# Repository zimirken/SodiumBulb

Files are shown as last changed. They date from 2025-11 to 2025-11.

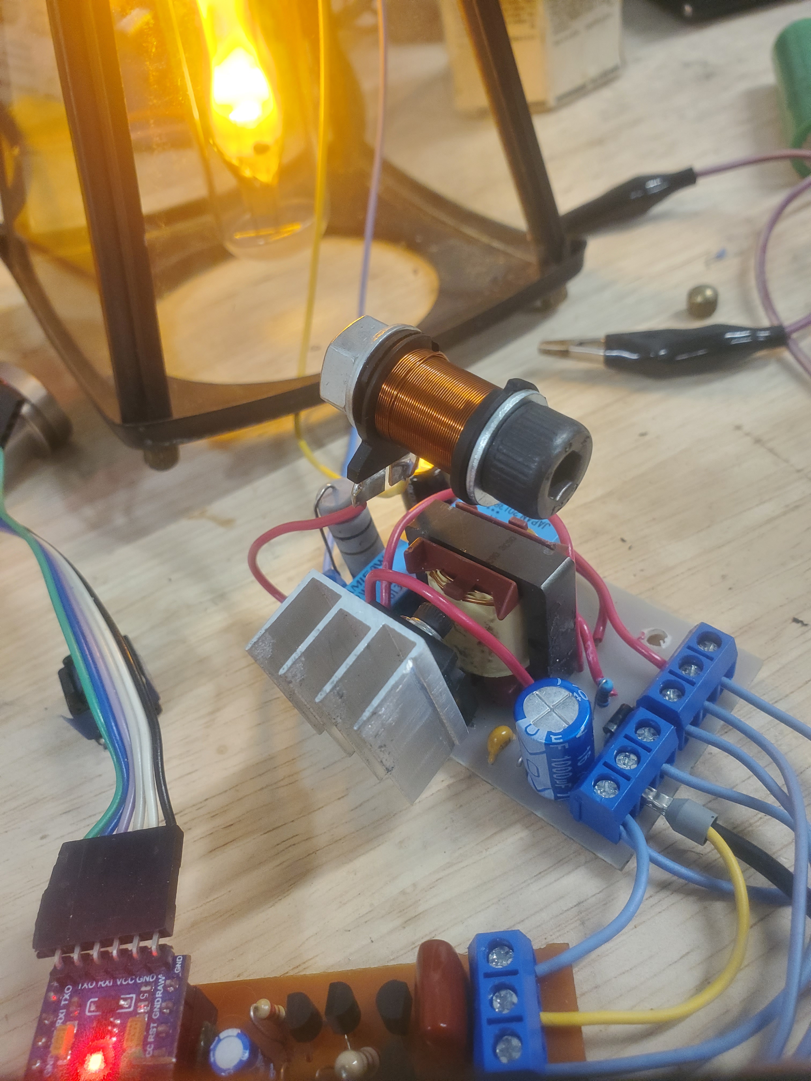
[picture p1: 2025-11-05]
20231208_142537.jpg

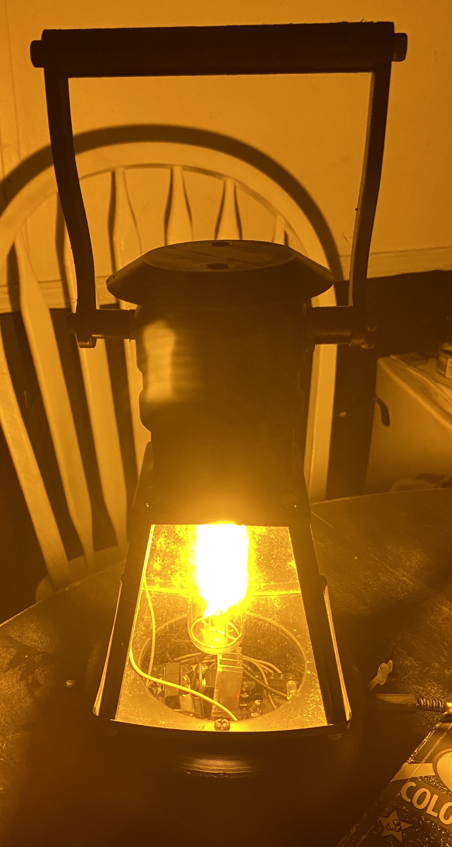
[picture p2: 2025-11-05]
IMG_0919.jpg

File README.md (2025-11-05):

# SodiumBulb
low pressure sodium vapor bulb
This is designed to drive a GP20NA or GP20ND low pressure sodium vapor bulb. 

These bulbs normally run on 15-20 volts at 1-2 amps. However, ignition is much more difficult. They require an ignition pulse of >400 volts with oomph behind it for a second or two in order to jump the gap between the main electrodes. This made designing a compact battery powered driver very difficult.

There is only one step up transformer in the circuit that serves dual purposes. During normal operation the secondary is disconnected and the primary is used as an inductor in a boost converter to generate the 15-20 volts to power the lamp. However during ignition, relays connect the secondary of the transformer to the bulb, and then the primary is driven HARD to get a discharge going across the electrode gap. The transformer and mosfet will overheat rapidly during this, but it only takes a couple seconds. It's also quite fun, as it gives you the feeling of igniting a flame lantern. When the lamp isn't ignited, the boost converter maintains the capacitor voltage at 35 volts. This extra voltage buffer gives the bulb a bit of extra juice to keep it lit while switching from ignite to drive.

The transformer was salvaged from a power supply, should be about a 10x step up. A transformer from one of those chinese 12V to 350V DC-DC boost converter boards should work. You will have to experiment with bulb polarity when hooking it to the circuit, Mine ignited much easier one way vs the other. NOT SHOWN on the schematic(but shown in pictures) is an inductor in series with the bulb. It's literally a coil of wire around an 8mm steel bolt. For me it made the bulb less likely to go out randomly, but wasn't required. In fact it looks like I might have not even included it in the final build. There's an enable terminal block, and an ignite terminal block. Jump the enable pins to enable the whole thing. Put a pushbutton switch on the ignite pins for igniting the bulb. The circuit and program has built in low voltage cutoff.

The 12 volt power in doesn't have its own connector on the boards, it is connected to pins 1(gnd) and 2(12v) on the GPG terminal block on the power board. Study the schematic and pictures to confirm.

Bulb: https://www.aliexpress.us/item/2255801048097192.html

A step file for the lantern assembly I built is included, but likely won't be super helpful. It's based on an outdoor house lamp I found at a thrift store.

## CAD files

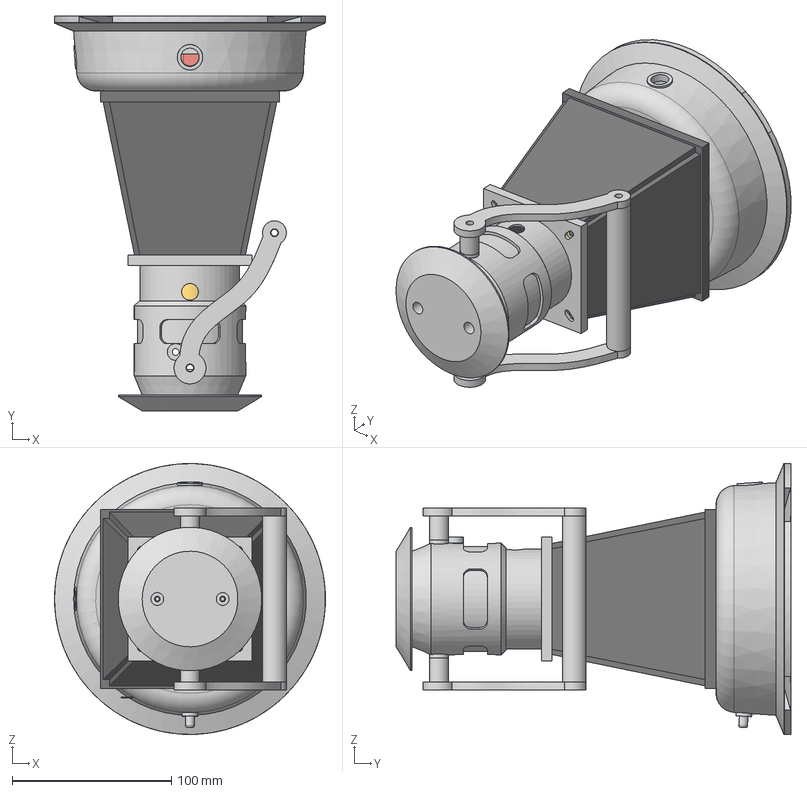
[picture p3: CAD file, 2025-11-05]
sodium lantern v25.step
170.0 x 247.8 x 170.0 mm
glass
bottom flange
bulb
socket
spacer x 2
top cap
bottom cap
base 1
base lid
decorative top cap
lower handle spacer x 2
handle arm x 2
handle
switch V-153-1C25
ignition button

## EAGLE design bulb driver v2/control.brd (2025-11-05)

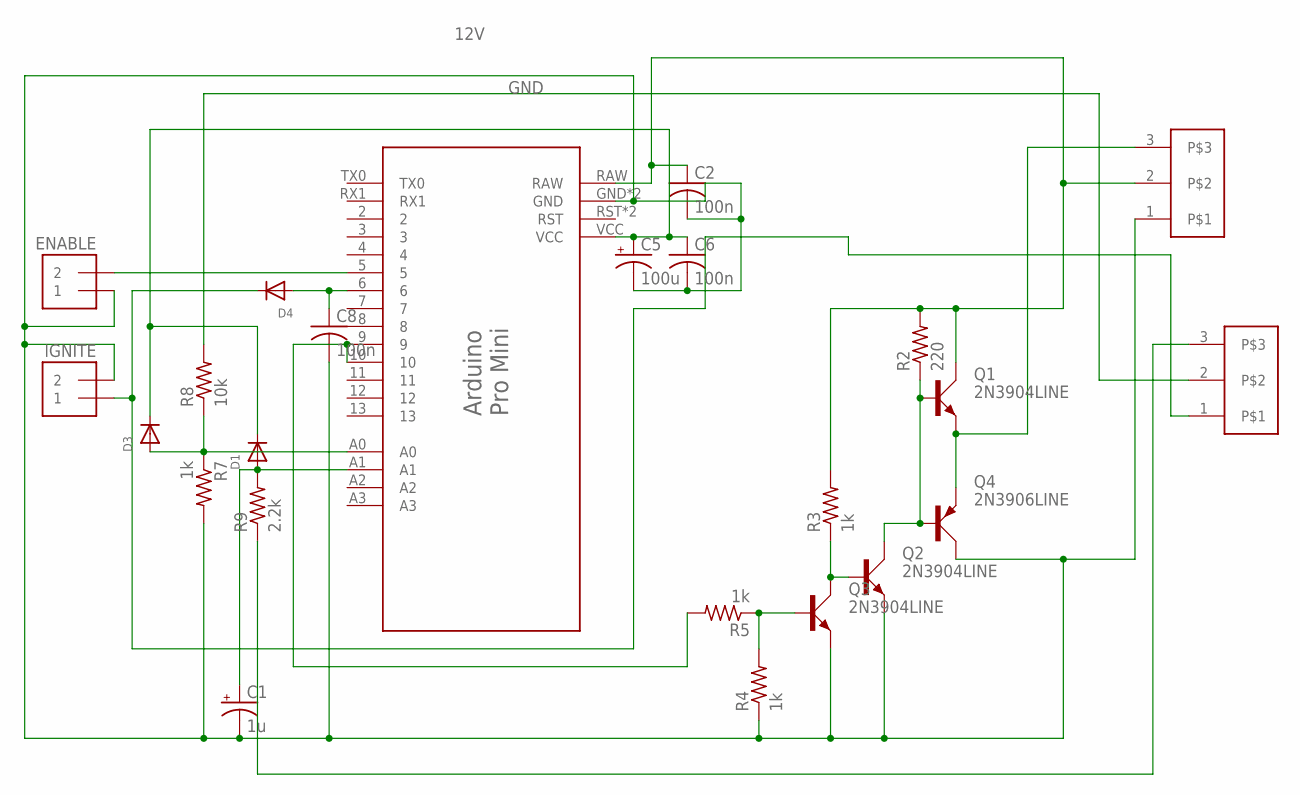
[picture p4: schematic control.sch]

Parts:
C1: 1u; E2,5-6
C2: 100n; C050-030X075
C5: 100u; E2,5-6
C6, C8: 100n; C050-025X075
D1, D3, D4: DIODEDO-1N4148; DO-1N4148
ENABLE: 1X2_12PINS; 1X2PINS
GPG: 1X3_123
IGNITE: 1X2_12HORZPINS; 1X2HORZ
IVI: 1X3_123
Q1, Q2, Q3: 2N3904LINE; TO92-LINE
Q4: 2N3906LINE; TO92-LINE
R2: 220; 0204/5
R3, R4: 1k; 0207/2V
R5: 1k; 0207/15
R7: 1k; 0207/5V
R8: 10k; 0207/15
R9: 2.2k; 0207/12
U$1: PRO_MINI

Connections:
12V: C2.1, GPG.2, Q1.C, R2.2, R3.2, U$1.RAW
GND: C1.-, C2.2, C5.-, C6.2, C8.2, ENABLE.1, GPG.1, IGNITE.2, Q2.E, Q3.E, Q4.C, R4.1, R7.2, U$1.GND, U$1.GND1 (GND)
unnamed: D3.A, R7.1, R8.1, U$1.A0
unnamed: C5.+, C6.1, D1.C, D3.C, U$1.VCC
unnamed: GPG.3, Q1.E, Q4.E
unnamed: Q3.B, R4.2, R5.1
unnamed: Q1.B, Q2.C, Q4.B, R2.1
unnamed: Q2.B, Q3.C, R3.1
unnamed: R5.2, U$1.9, U$1.10
unnamed: C1.+, D1.A, R9.2, U$1.A1
unnamed: IVI.3, R9.1
unnamed: IVI.2, R8.2
unnamed: ENABLE.2, U$1.5
unnamed: C8.1, D4.A, U$1.6
unnamed: D4.C, IGNITE.1, IVI.1

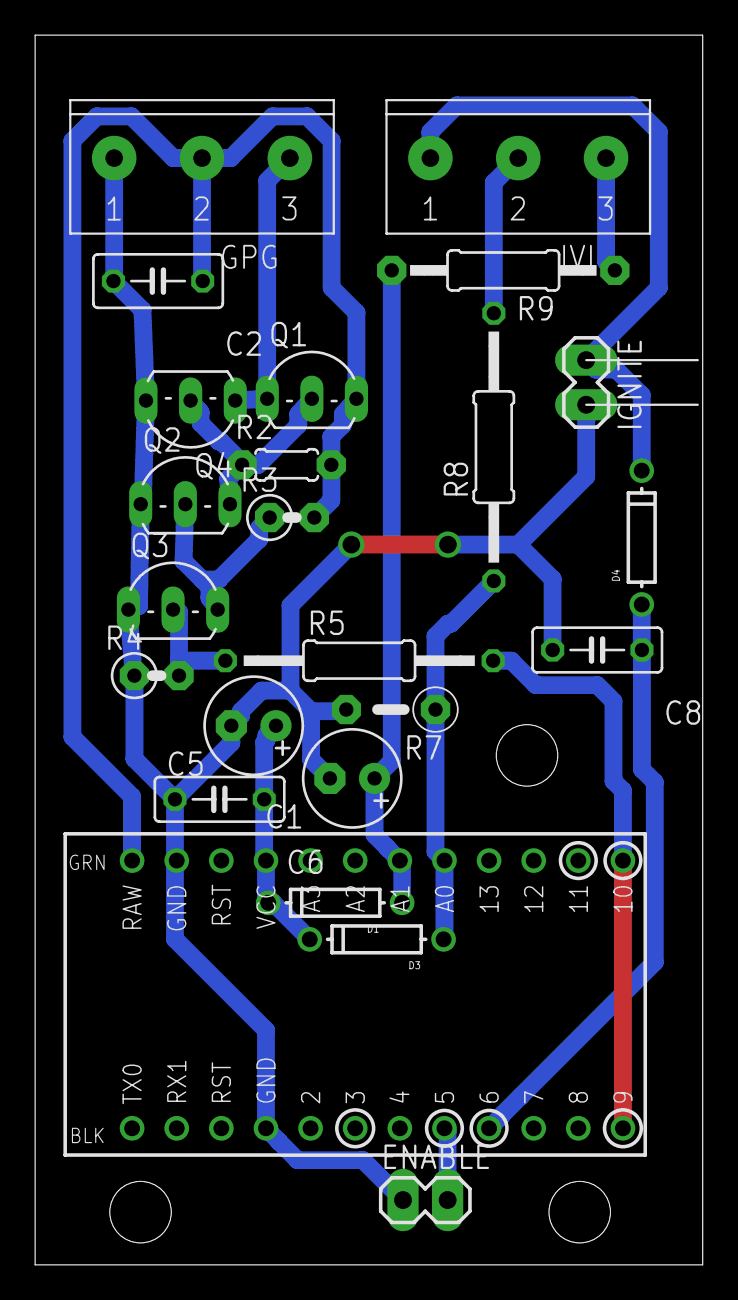
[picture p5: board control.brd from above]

Board: 2 copper layers, 38.0 x 70.0 mm, 24 parts (0 on the bottom side), 15 nets.

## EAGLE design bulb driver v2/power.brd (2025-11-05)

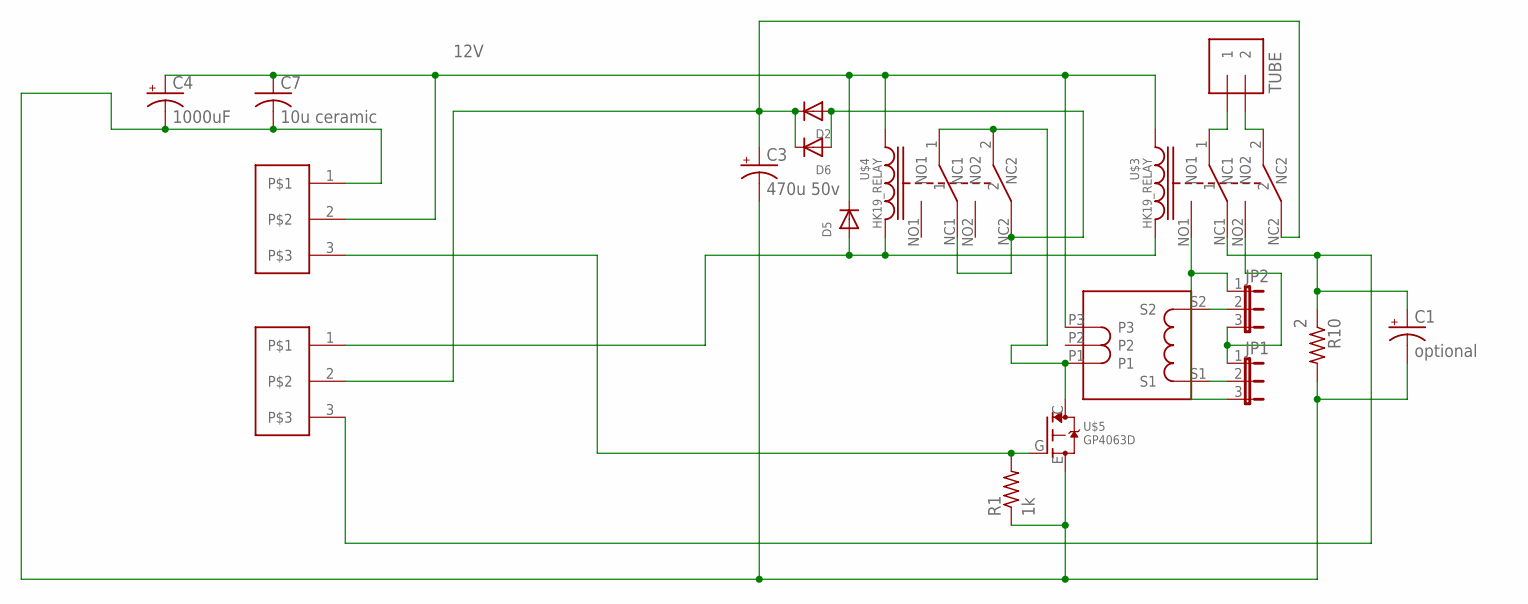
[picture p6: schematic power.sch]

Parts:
C1: optional; E2,5-6
C3: 470u 50v; E5-10,5
C4: 1000uF; E5-10,5
C7: 10u ceramic; C050-045X075
D2, D5, D6: DIODEDO-1N4148; DO-1N4148
GPG: 1X3_123
IVC: 1X3_123
JP1, JP2: JP2E; JP2
R1: 1k; 0204V
R10: 2; P0817V
TUBE: 1X2_1221; 1X2_21
U$2: TRANSFORMER_RAND_1
U$3, U$4: HK19_RELAY; HK19RELAY
U$5: GP4063D; TO247

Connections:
12V: C4.+, C7.1, D5.C, GPG.2, U$2.P3, U$3.C1, U$4.C1
GND: C1.-, C3.-, C4.-, C7.2, GPG.1, R1.1, R10.2, U$5.E
unnamed: TUBE.1, U$3.1
unnamed: TUBE.2, U$3.2
unnamed: JP2.2, U$2.S2
unnamed: JP1.2, U$2.S1
unnamed: U$2.P1, U$4.1, U$4.2, U$5.C
unnamed: GPG.3, R1.2, U$5.G
unnamed: JP1.3, JP2.1, U$3.NO1
unnamed: JP1.1, JP2.3, U$3.NO2
unnamed: D2.A, D6.A, U$4.NC1, U$4.NC2
unnamed: C1.+, IVC.3, R10.1, U$3.NC1
unnamed: C3.+, D2.C, D6.C, IVC.2, U$3.NC2
unnamed: D5.A, IVC.1, U$3.C2, U$4.C2

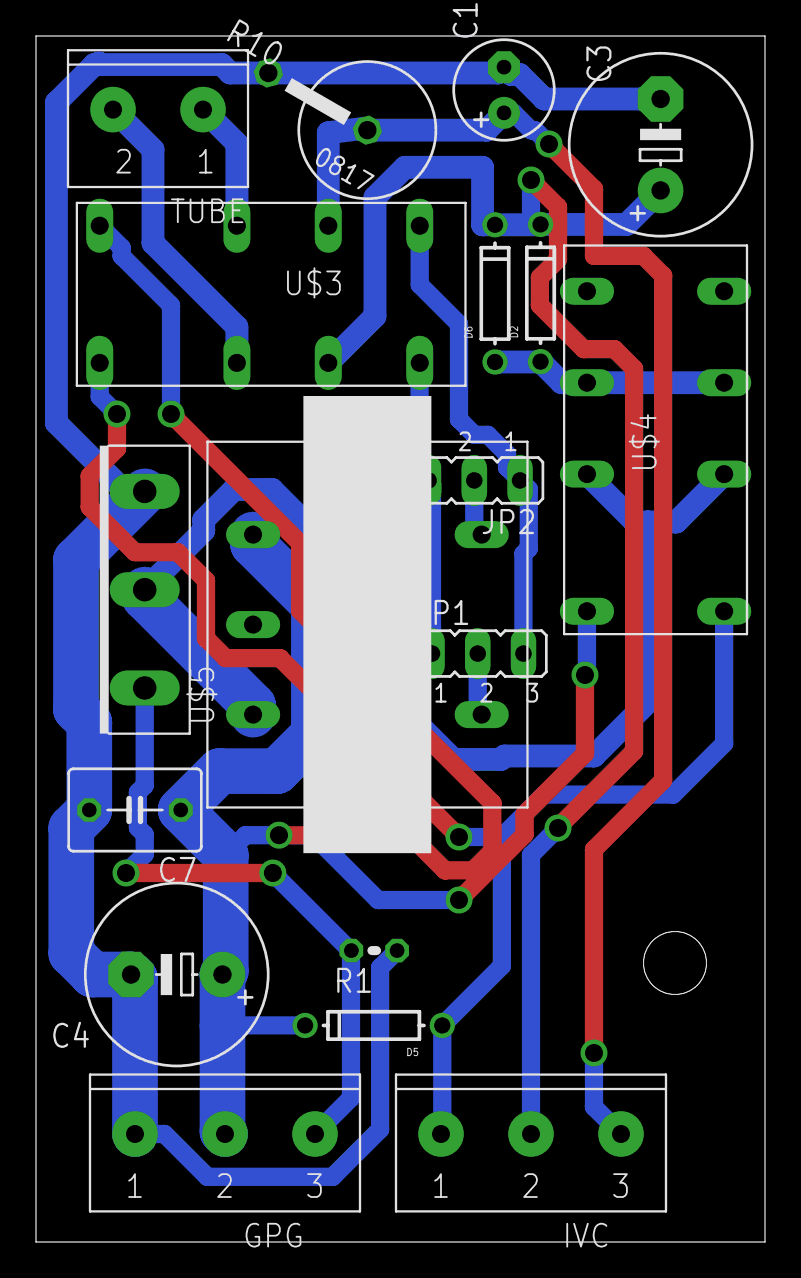
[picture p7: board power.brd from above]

Board: 2 copper layers, 40.5 x 67.0 mm, 18 parts (0 on the bottom side), 14 nets.

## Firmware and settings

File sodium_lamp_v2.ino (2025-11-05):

Sodium vapor bulb driver

#include <AsyncDelay.h>
AsyncDelay delay_3s;
#include "RunningAverage.h"

RunningAverage myRA(3);

static float senseresistor = 2.1;//sense resistor ohms
static float maxcurrent = 1075.0;//maximum/target current in Milliamps
static float referencevoltage = 5.0;//internal reference voltage for your arduino chip
static int analogreadresolution = 1024;//resolution of your analog read

static float topresistor = 10000; //top resistor on divider
static float bottomresistor = 1000;//bottom resistor
static float maxvoltage = 32.0;
static int hyst = 50;


static int voltagePin = A0;
static int currentPin = A1;
static int pwmPin = 10;
static int enablePin = 5;
static int ignitePin = 6;
static int idlePin = 12;

static int vmax = (maxvoltage*(bottomresistor/(topresistor+bottomresistor)))*(analogreadresolution/referencevoltage); 
//(sense resistor ohms * desired max current)/(internal voltage reference / analog read resolution)


static int pwmMax = 180;
static int pwmmin = 80;
static int pwmIgniteStart = 120;
static int pwmIgniteMax = 180;
int pwmOut = 9;
int disableMin = 0;
int disableMax = 0;

float voltage = 0;
int lastCurrent = 0;
int current = 0;

//low voltage cutoff
static int batVoltagePin = A4;
static float BRTop = 100000;
static float BRBottom = 22000;
int lowVoltageCount = 0;

static float LVCutoff = 10.5; //low voltage cutoff, set for lead acid batteries.


void setup() {
  // put your setup code here, to run once:
//pinMode(red,OUTPUT);
//pinMode(green,OUTPUT);
Serial.begin(9600);
digitalWrite(pwmPin, LOW);
pinMode(pwmPin,OUTPUT);
pinMode(enablePin, INPUT_PULLUP);
pinMode(ignitePin, INPUT_PULLUP);
delay_3s.start(3000, AsyncDelay::MILLIS);
myRA.clear(); // explicitly start clean
pinMode(idlePin, OUTPUT);
digitalWrite(idlePin, HIGH);
// Pins D9 and D10 - 31.4 kHz
TCCR1A = 0b00000001; // 8bit
TCCR1B = 0b00000001; // x1 phase correct
// Pins D9 and D10 - 62.5 kHz
//TCCR1A = 0b00000001; // 8bit
//TCCR1B = 0b00001001; // x1 fast pwm
// Pins D9 and D10 - 15.6 kHz 10bit
//TCCR1A = 0b00000011; // 10bit
//TCCR1B = 0b00001001; // x1 fast pwm
}

void loop() {

readPower();  //reads the voltage and current inputs

if(digitalRead(enablePin) == LOW){
  if(digitalRead(ignitePin) == LOW){//ignition
    int ignitePwm = pwmIgniteStart;
    while(digitalRead(ignitePin) == LOW){
      analogWrite(pwmPin, ignitePwm);
      if(ignitePwm < pwmIgniteMax) {
        ignitePwm++;
        delay(10);
      }
      Serial.print("ignite pwm: ");
      Serial.println(ignitePwm);
    }
    pwmOut = pwmMax;
    myRA.clear();
  }
  //end of ignition
  else{//normal running
    driveLamp();
  }
}
else {//if lamp is not enabled
  digitalWrite(pwmPin, LOW);
  digitalWrite(13, HIGH);
}

if(current < 100) {//visual feedback for current load
  digitalWrite(idlePin, HIGH);
}
else {
  digitalWrite(idlePin, LOW);
}


if (delay_3s.isExpired()) {

    if(lowVoltageCheck() == 1) {
      lowVoltageCount = lowVoltageCount++;
    }
    else{
      lowVoltageCount = 0;
    }

    if(lowVoltageCount > 3){
      digitalWrite(pwmPin, LOW);
      
      while(true){
        digitalWrite(idlePin, HIGH);
        delay(1000);
        digitalWrite(idlePin, LOW);
        delay(1000);
      }
    }
    
    Serial.print("Voltage: ");
    Serial.print(voltage);
    Serial.print(" ,Current: ");
    Serial.print(current);
    Serial.print(" ,disableMin: ");
    Serial.print(disableMin);    
    Serial.print(" ,disableMax: ");
    Serial.print(disableMax);    
    Serial.print(" ,pwm: ");
    Serial.println(pwmOut);

    
    delay_3s.repeat(); // Count from when the delay expired, not now
  }


//delay(1);
}

void readPower() {//reads the voltage and current
  voltage = (analogRead(voltagePin)*referencevoltage/analogreadresolution)*(topresistor+bottomresistor)/bottomresistor;
  lastCurrent = map(analogRead(currentPin),0,1024,0,(referencevoltage/senseresistor*1000));
  myRA.addValue(lastCurrent);
  current = myRA.getAverage();
}

void driveLamp() {//does the actual driving of the lamp
      if(lastCurrent < (maxcurrent-hyst) && pwmOut < pwmMax) {
      pwmOut++;
      pwmOut++;
    }
    if(current > (maxcurrent+hyst) && pwmOut > 0){
      if(disableMin < 2000 && pwmOut > pwmmin) {
        pwmOut--;
      }
      else if(disableMin > 2000){
        pwmOut--;
      }
    }
    if(current > (maxcurrent+hyst) && pwmOut <= pwmmin) {
      disableMin++;
    }
    else if(current < (maxcurrent+hyst) && disableMin > 0) {
      disableMin--;
    }
    if(voltage < maxvoltage) {
      analogWrite(pwmPin, pwmOut);
      if(pwmOut >= pwmMax) {
        disableMax++;
      }
      else if(disableMax > 0) {
        disableMax--;
      }
    }
    if(voltage > maxvoltage) {
      digitalWrite(pwmPin, LOW);
      disableMax = 0;
    }
    if (disableMax > 2000) {
      digitalWrite(pwmPin, LOW);
      delay(10000);
    }
    if (pwmOut >= pwmMax) {
      digitalWrite(13,LOW);
    }
    else {
      digitalWrite(13,HIGH);
    }
}

bool lowVoltageCheck() {//monitor battery voltage and check for low voltage. if voltage is low, enter shutdown loop.
  float batVoltage = (analogRead(batVoltagePin)*referencevoltage/analogreadresolution)*(BRTop+BRBottom)/BRBottom;
  if(batVoltage < LVCutoff && batVoltage > 1) {
    return 1;
  }
  else{
    return 0;
  }
}
